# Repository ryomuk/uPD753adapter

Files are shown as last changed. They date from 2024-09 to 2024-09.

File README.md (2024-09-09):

# uPD753adapter
Adapter for NEC uPD753 to convert to Intel 8080 pinout.

## 概要
- NEC uPD753を8080のピン配列にするためのアダプタです．

## 基板
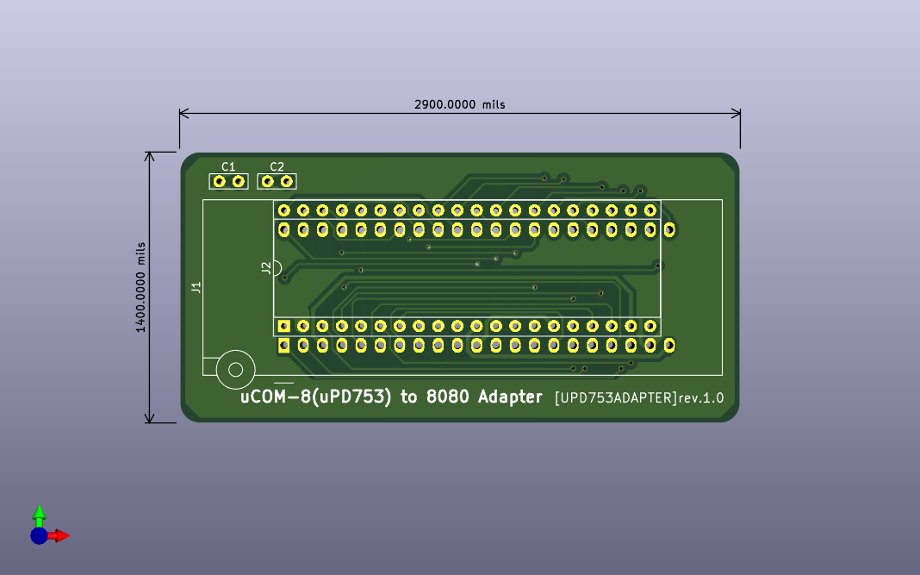
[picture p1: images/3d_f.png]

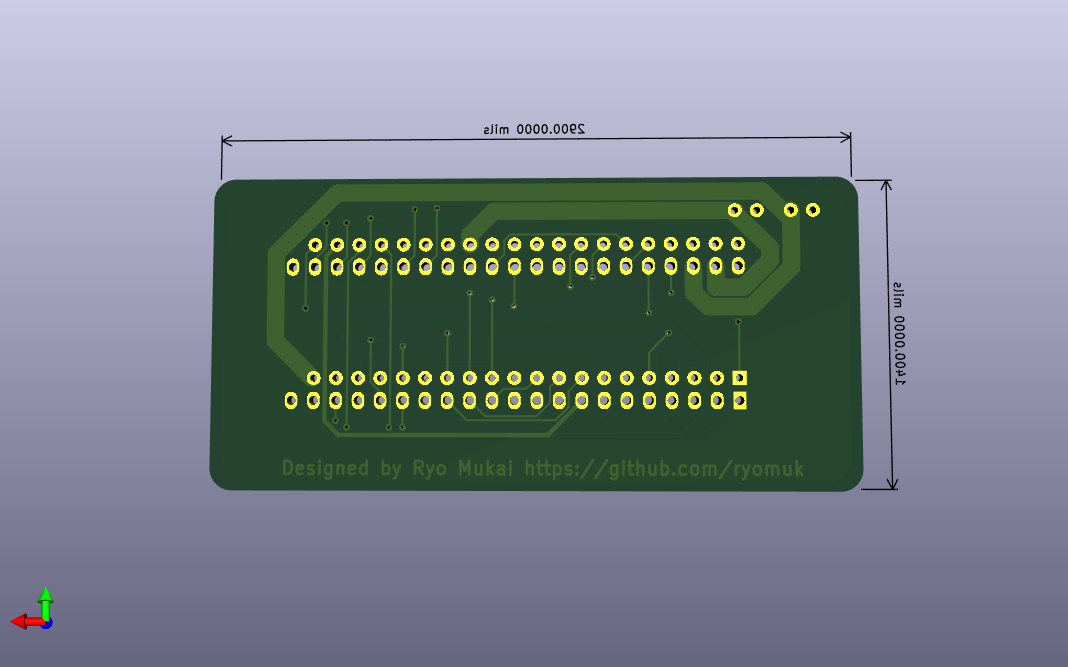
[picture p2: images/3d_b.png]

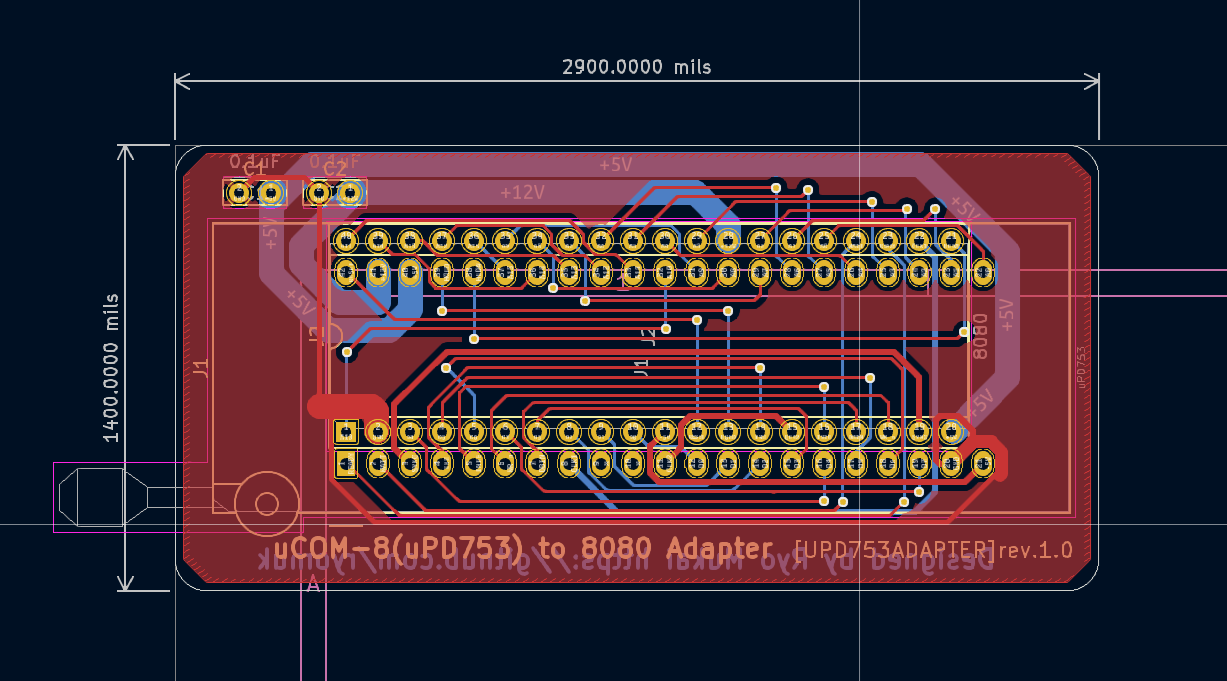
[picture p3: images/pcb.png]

- 実物
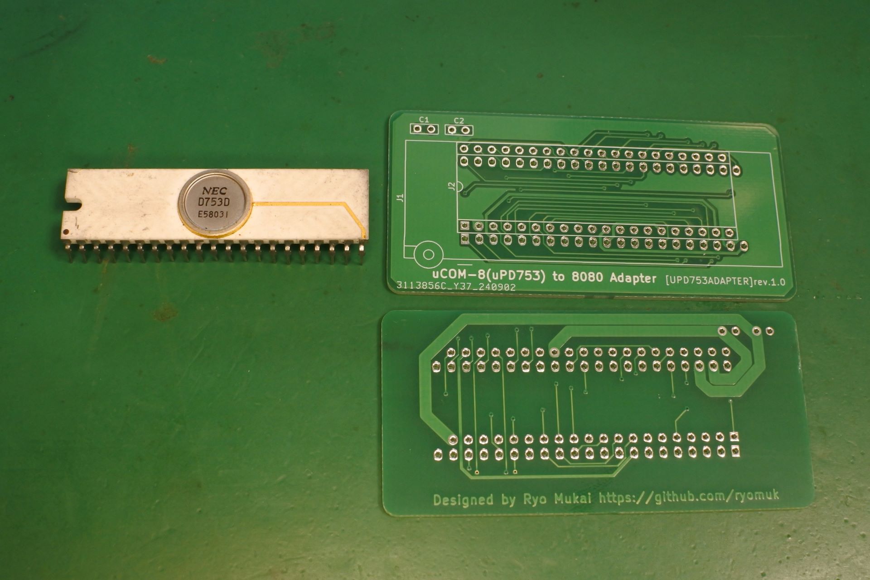
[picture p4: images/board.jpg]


### BOM
|Reference |Qty| Value |Memo |
|---|---|---|-----|
|C1,C2 |2  |0.1uF | |
|J1 |1  |42pin ZIF Socket|uPD753用ソケット |
|J2 |1  |40pinの何か |8080側端子 |

## 動作例
- [TangNano8080MEM](https://github.com/ryomuk/tangnano-5V/tree/main/applications/TangNano8080MEM)に載せてみたところ，問題無く動作しました．

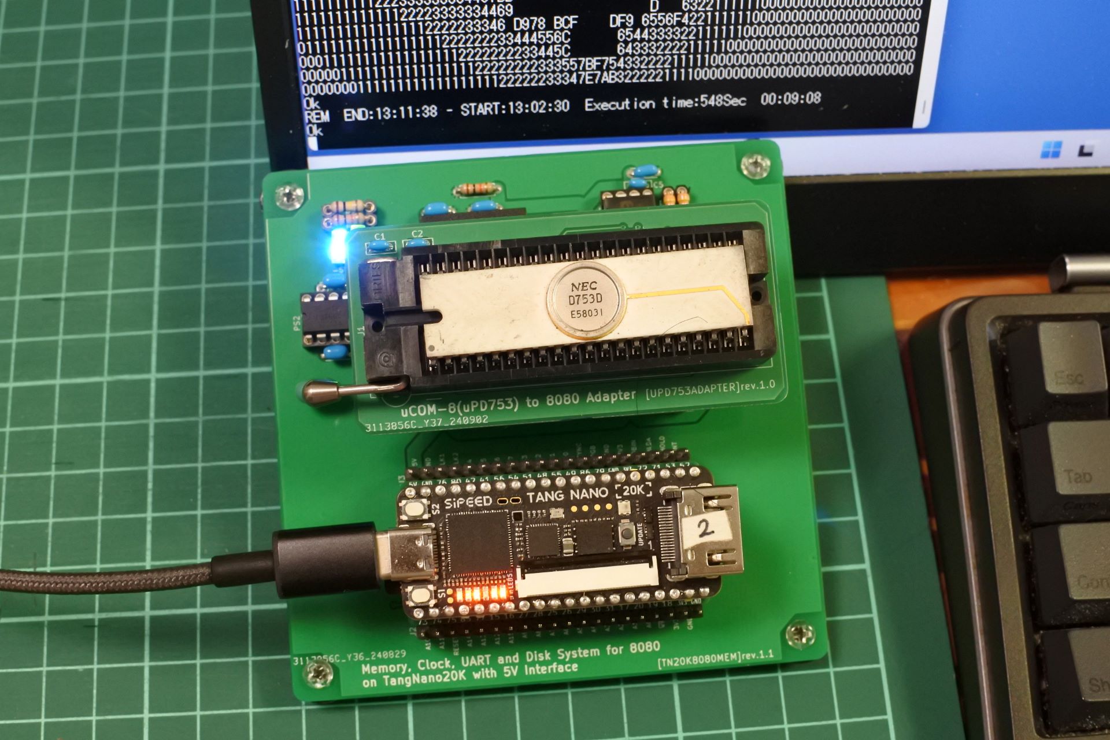
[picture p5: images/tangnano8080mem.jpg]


## 関連情報
- uCOM-8 [www.st.rim.or.jp/~nkomatsu/nec/uPD753.html](http://www.st.rim.or.jp/~nkomatsu/nec/uPD753.html)
- NEC μCOMシリーズ総合ユーザーズガイド 1978 SUMMER pp.32-33
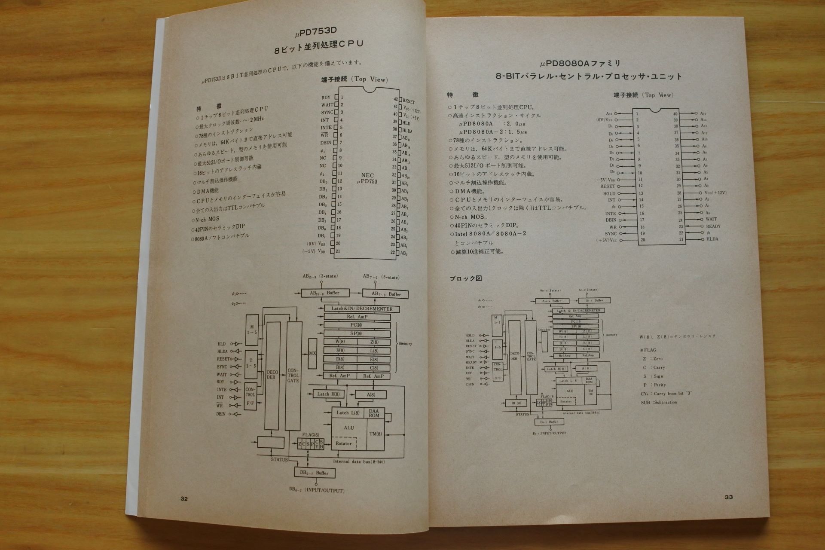
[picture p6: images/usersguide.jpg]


## 更新履歴
- 2024/09/09: 初版公開

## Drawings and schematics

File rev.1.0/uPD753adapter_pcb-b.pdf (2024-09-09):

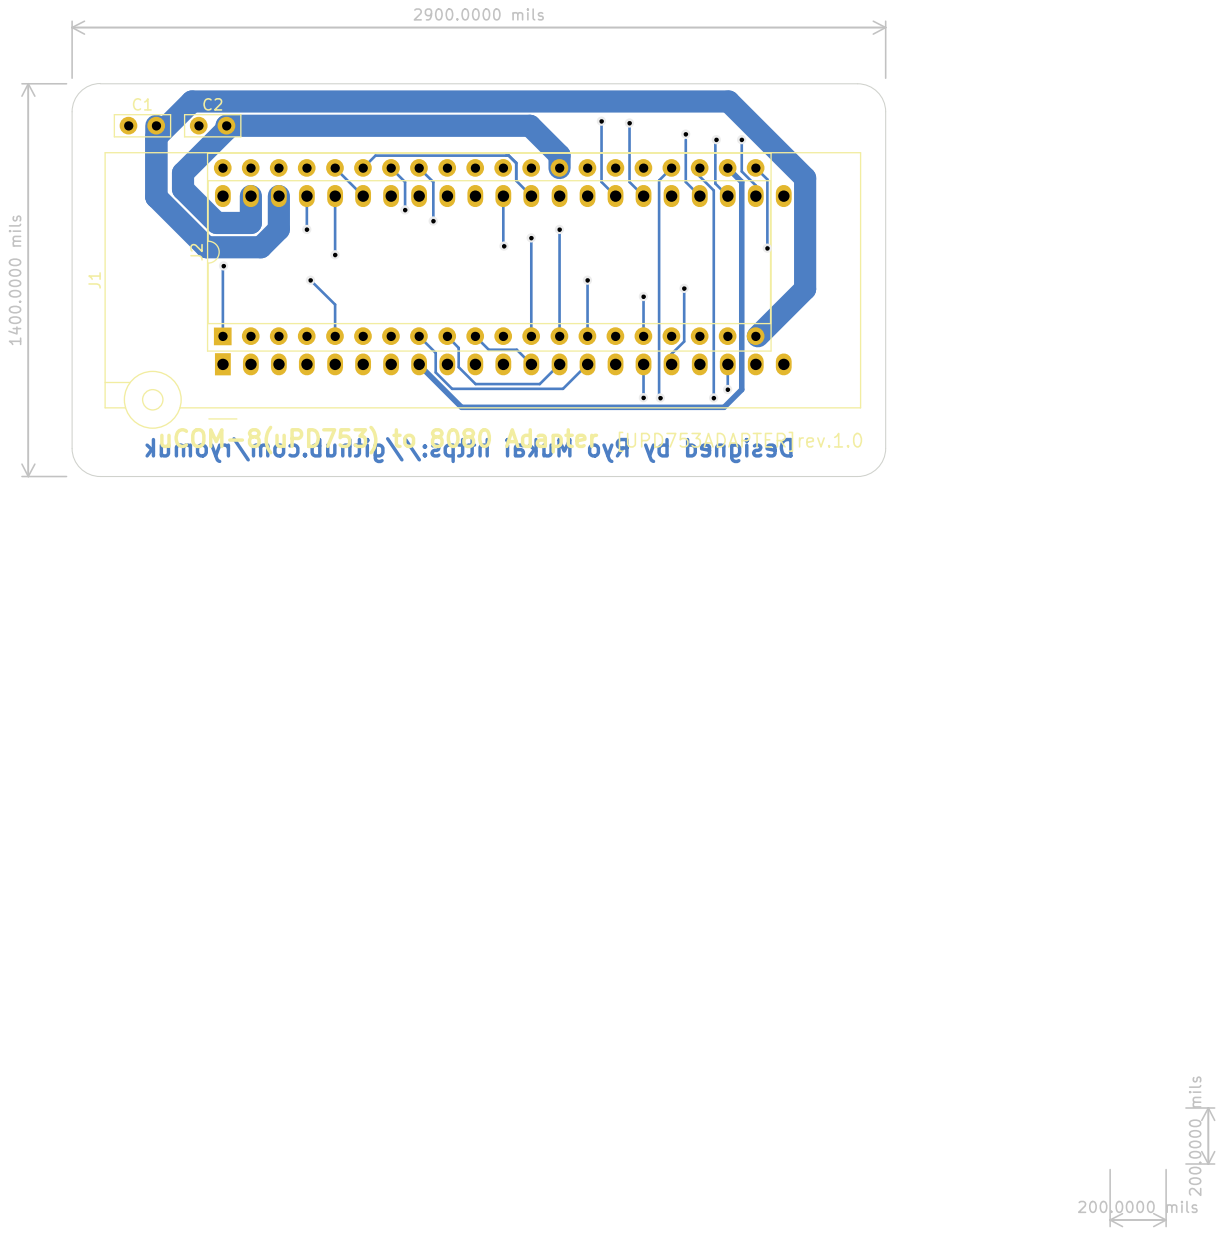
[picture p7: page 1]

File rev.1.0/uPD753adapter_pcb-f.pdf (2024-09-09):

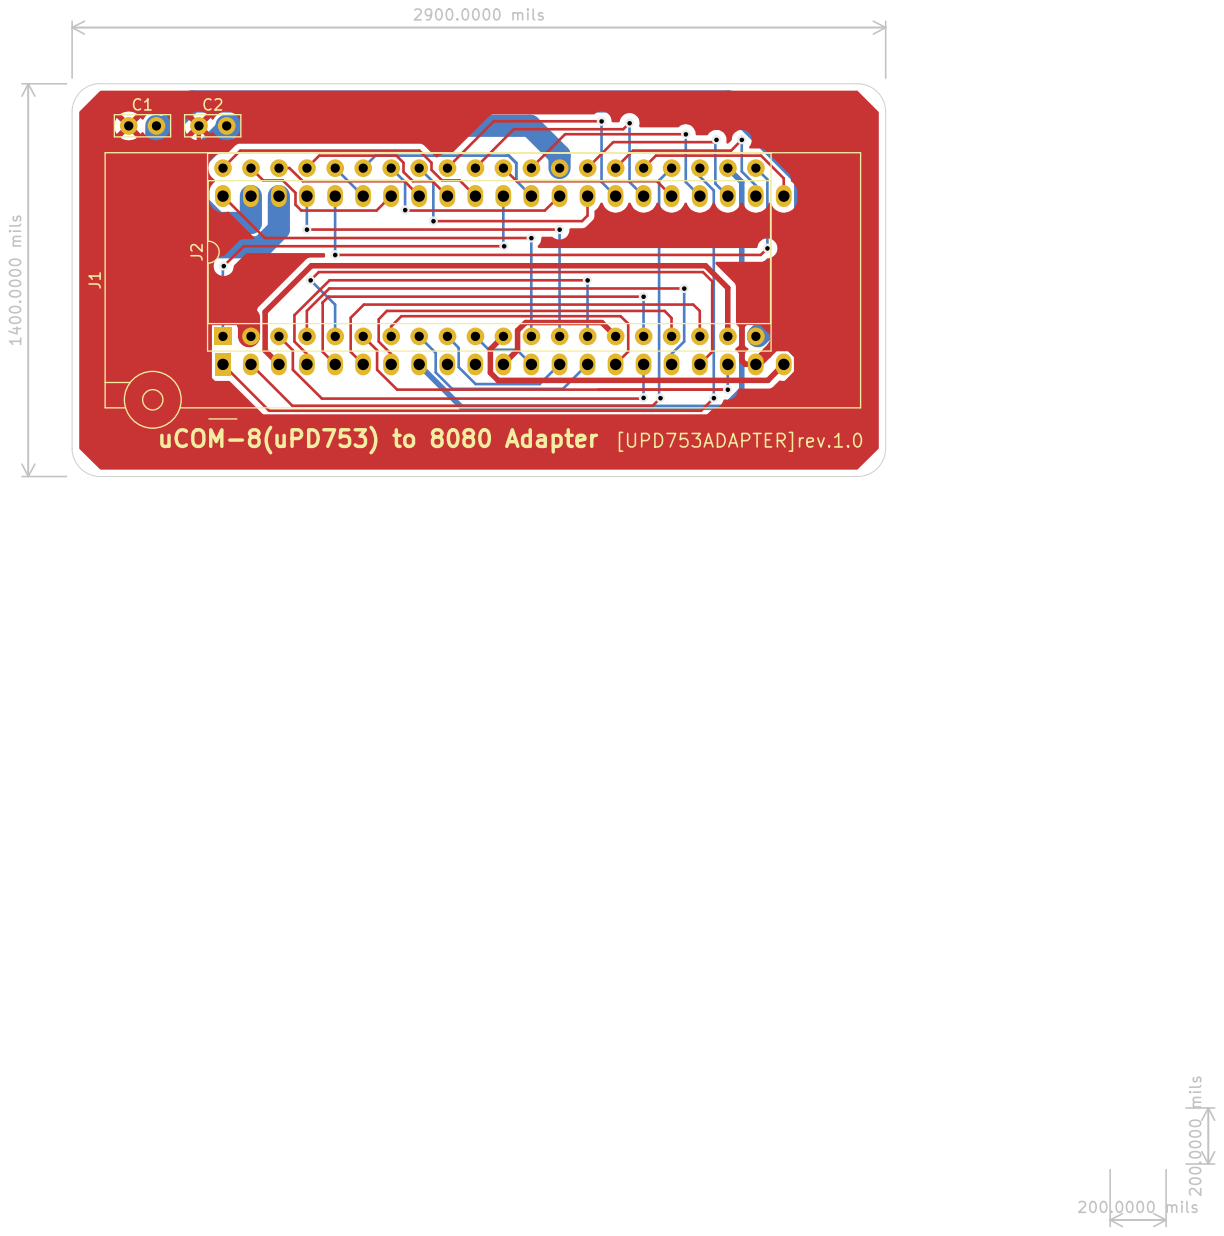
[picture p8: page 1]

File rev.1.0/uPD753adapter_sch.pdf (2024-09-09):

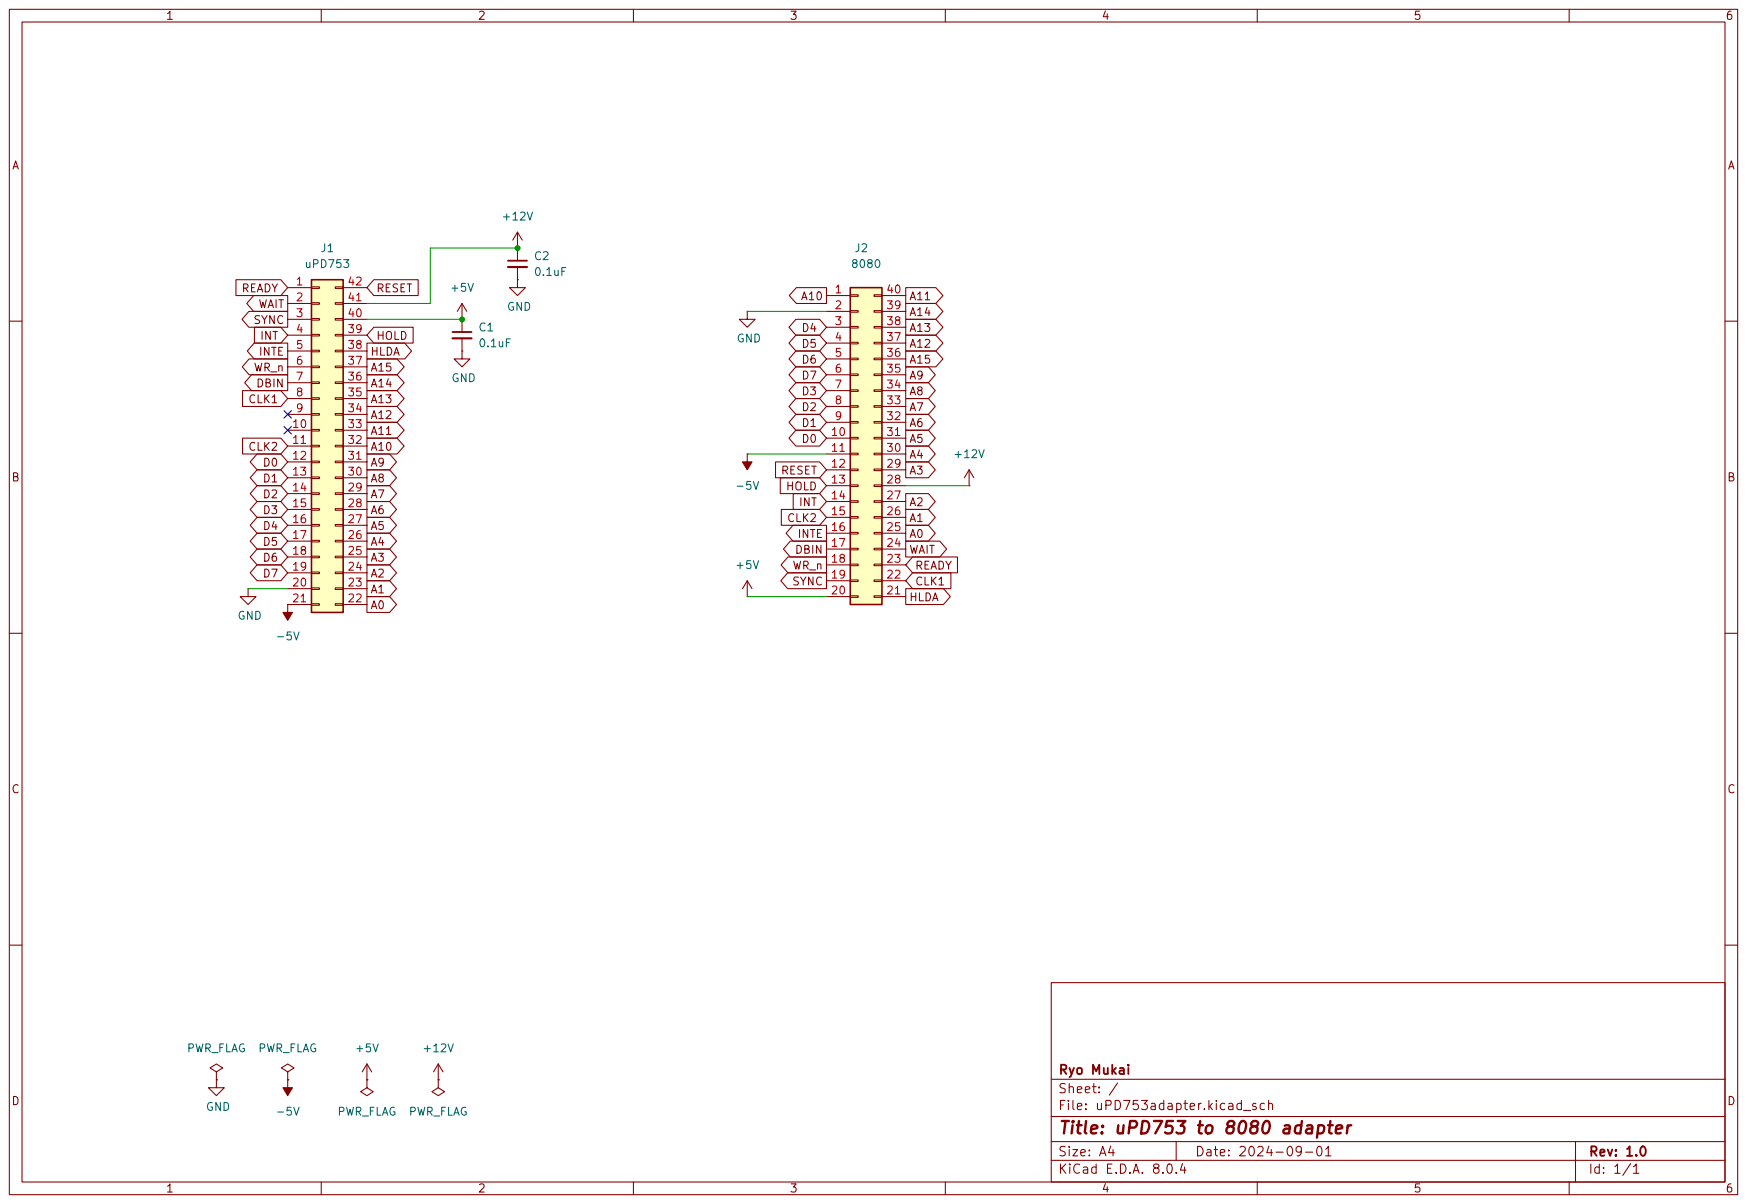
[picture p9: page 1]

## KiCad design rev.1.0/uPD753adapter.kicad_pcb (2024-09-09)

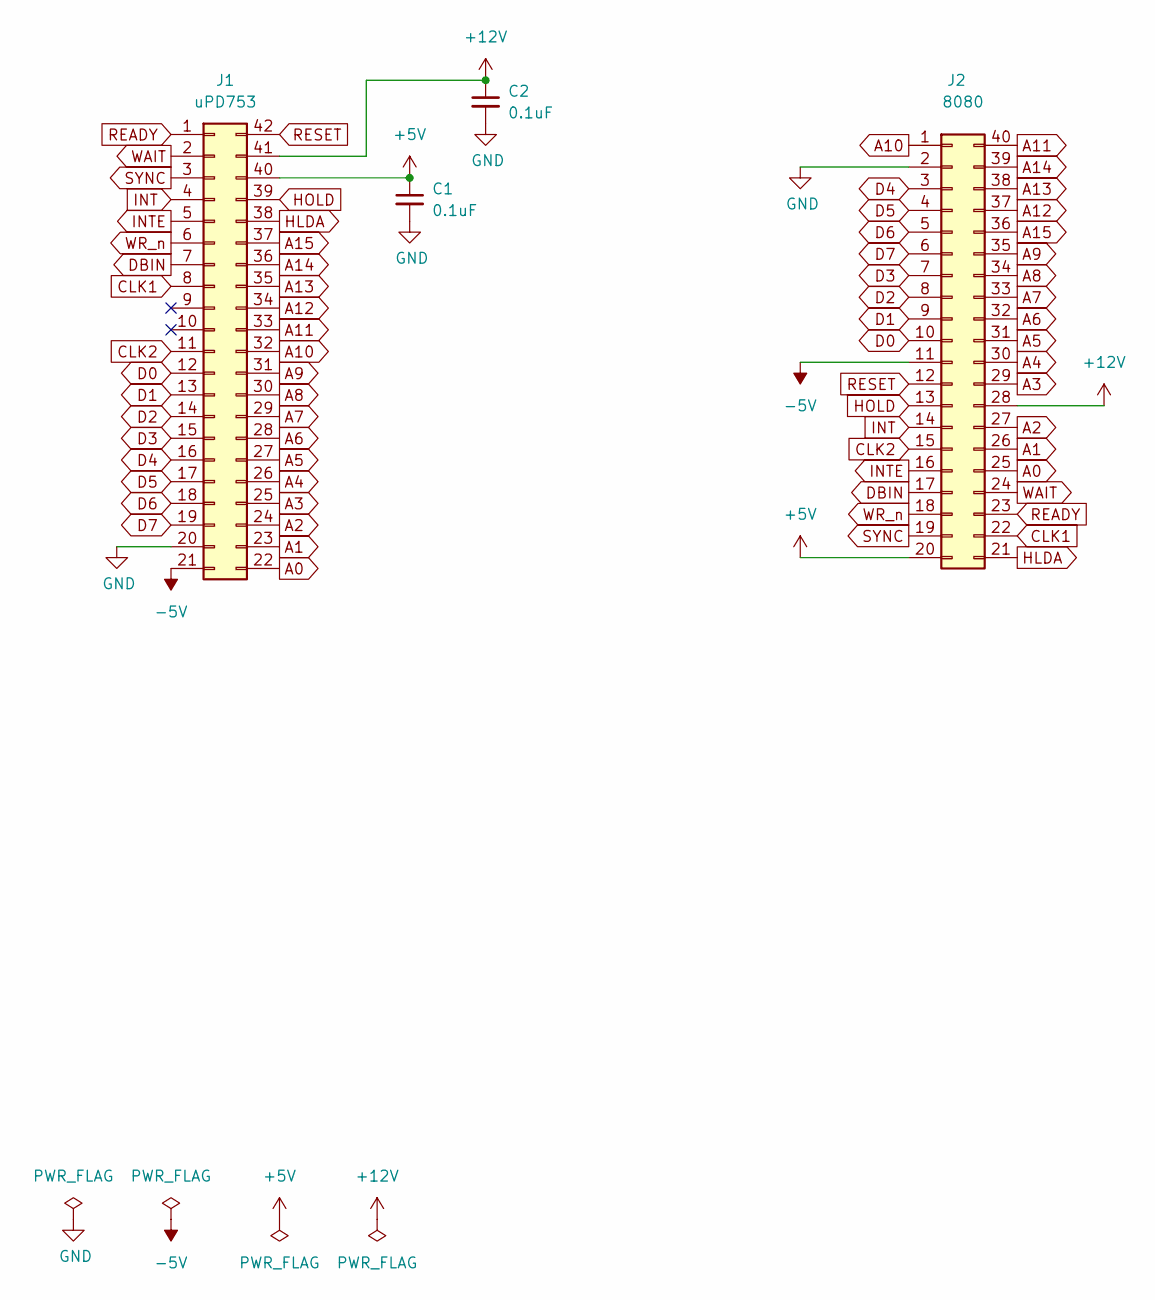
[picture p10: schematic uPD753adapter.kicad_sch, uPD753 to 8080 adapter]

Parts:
C1, C2: 0.1uF; C_Disc_D5.0mm_W2.5mm_P2.50mm
J1: uPD753; DIP_Socket-42_W11.9_W12.7_W15.24_W17.78_W18.5_3M_242-1281-0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
J2: 8080; DIP-40_W15.24mm_Socket

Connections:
+5V: C1.1, J1.40, J2.20
+12V: C2.1, J1.41, J2.28
-5V: J1.21, J2.11
A0: J1.22, J2.25
A1: J1.23, J2.26
A2: J1.24, J2.27
A3: J1.25, J2.29
A4: J1.26, J2.30
A5: J1.27, J2.31
A6: J1.28, J2.32
A7: J1.29, J2.33
A8: J1.30, J2.34
A9: J1.31, J2.35
A10: J1.32, J2.1
A11: J1.33, J2.40
A12: J1.34, J2.37
A13: J1.35, J2.38
A14: J1.36, J2.39
A15: J1.37, J2.36
CLK1: J1.8, J2.22
CLK2: J1.11, J2.15
D0: J1.12, J2.10
D1: J1.13, J2.9
D2: J1.14, J2.8
D3: J1.15, J2.7
D4: J1.16, J2.3
D5: J1.17, J2.4
D6: J1.18, J2.5
D7: J1.19, J2.6
DBIN: J1.7, J2.17
GND: C1.2, C2.2, J1.20, J2.2
HLDA: J1.38, J2.21
HOLD: J1.39, J2.13
INT: J1.4, J2.14
INTE: J1.5, J2.16
READY: J1.1, J2.23
RESET: J1.42, J2.12
SYNC: J1.3, J2.19
WAIT: J1.2, J2.24
WR_n: J1.6, J2.18

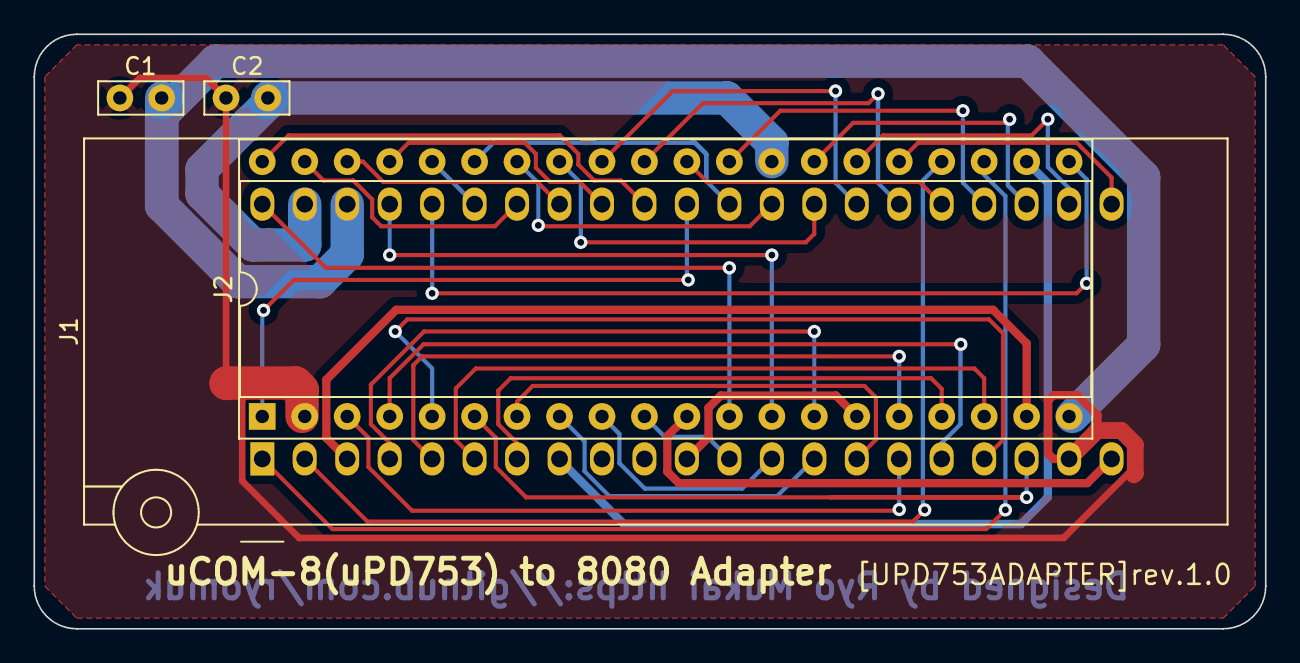
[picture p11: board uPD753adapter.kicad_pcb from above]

Board: 2 copper layers, 73.7 x 35.6 mm, 4 parts (0 on the bottom side), 40 nets.
